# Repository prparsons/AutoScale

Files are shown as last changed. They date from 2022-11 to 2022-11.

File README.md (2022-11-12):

# AutoScale
Automatic electronic scale.  This has mainly just been a project for fun, started simply with getting a load cell working on an MSP430. Eventually decided to try and make an auto dispensing scale (powder/granules). It grew beyond the capability of the MSP pretty quickly, at which point I moved to a STM32F405. Then I replaced the 16x2 character display with a 320x240 LCD (using an spi interface, so we could ditch the MSP that was running the 16x2 display previously)

Consists of a dump chamber for bulk volume, and an auger to precisely top up to desired weight.  Initial test with just the auger here: https://youtu.be/iJeQbjNJ7Eg

I have tried several 3d printed builds for this, none of which never were terribly practical (3d printer not tight enough tolerances). Most recent version should be in the CAD folder (currently aiming for something that can be easily milled via 3 axis CNC, in addition to 3d printed). 

Code compiled using Ti CCS version 10 and STM32CubeIDE version 1.8.0

# Parts List
- Load Cell (TAL221 100g) https://www.sparkfun.com/products/14727
- Load Cell Amplifier (HX711) https://www.sparkfun.com/products/13879
- Precision Voltage Reference (LM4040) https://www.adafruit.com/product/2200
- Microcontrollers
  - STM32F4 (Currently using STM32F405) https://www.sparkfun.com/products/17713
  - MSP430 Launchpad (MSP430G2553) 
- Motors
  - Nema 17 motors
    - https://www.amazon.com/dp/B07LF898KN?ref=ppx_yo2_dt_b_product_details&th=1
    - https://www.amazon.com/dp/B094CQDDKF?psc=1&ref=ppx_yo2_dt_b_product_details
  - Stepper Driver (Toshiba TC78H670FTG) https://www.sparkfun.com/products/16836
- LCD Display
  - 2.4" 320x240 LCD Display using a IL9341 controller
    - https://www.waveshare.com/2.4inch-LCD-Module.htm  (also available on amazon)
- 4x4 Button Array
- Breadboard(s)
- Lots of jumper wires
- i2c pullup resistors (docs specify 10k ohm; currently using 2 2.2k in series and its working fine)
  
# Display Code
Using Waveshare's provided code for the LCD display ( https://www.waveshare.com/wiki/2.4inch_LCD_Module#Using_with_STM32 )

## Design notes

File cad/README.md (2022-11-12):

Current auger is offset, that isn't necessary anymore, but doesn't really matter for now (it works fine offset).

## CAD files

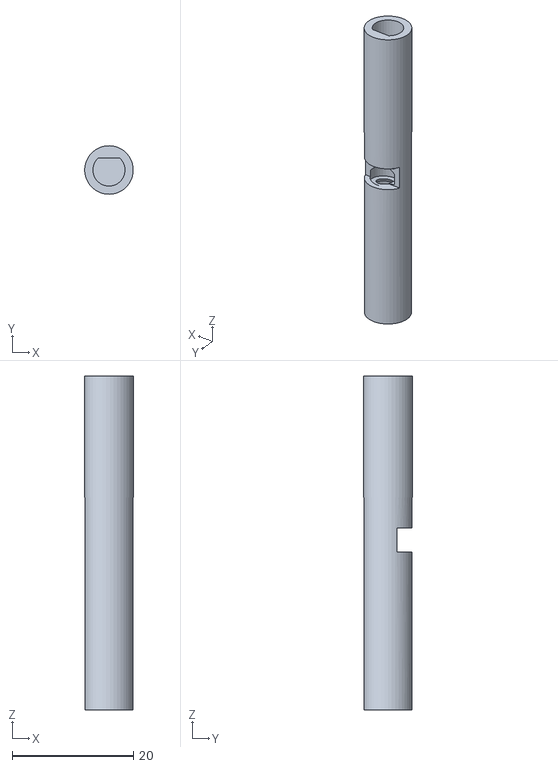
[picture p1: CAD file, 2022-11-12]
cad/measure_auger_tube.stl
7.99 x 7.99 x 55.0

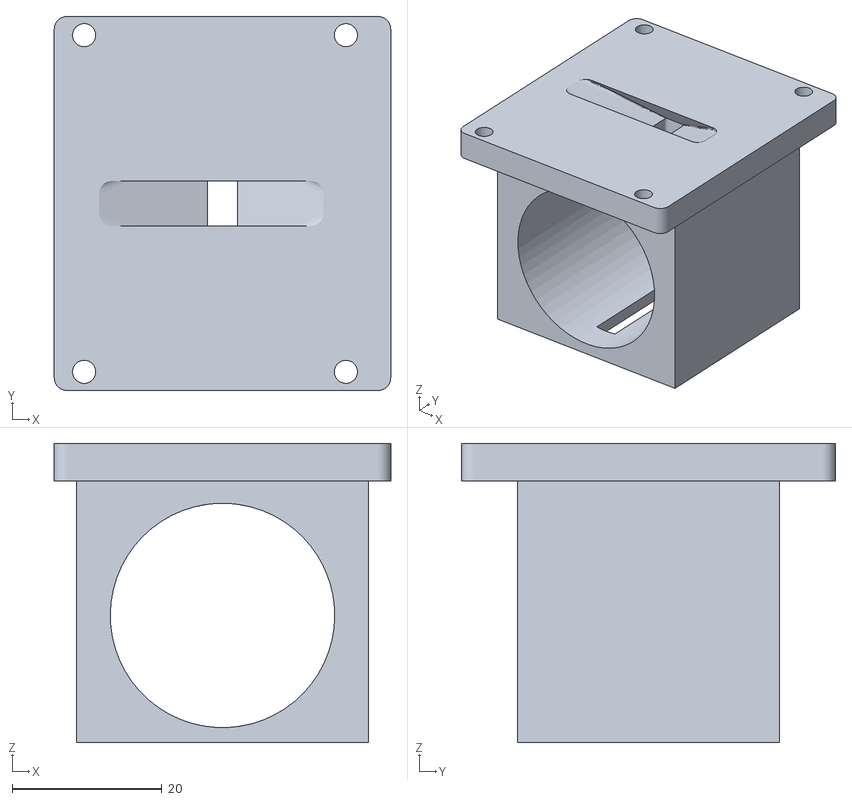
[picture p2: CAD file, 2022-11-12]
cad/measure_dump_body.stl
45.0 x 50.0 x 40.0

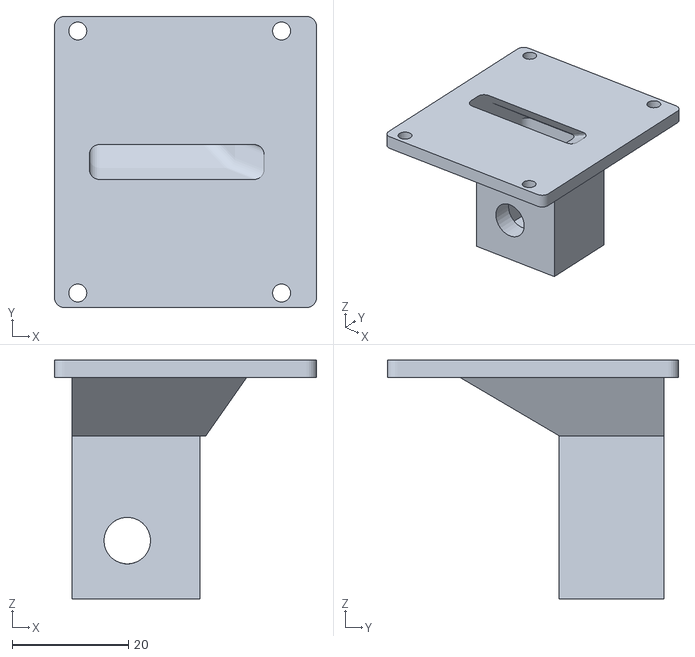
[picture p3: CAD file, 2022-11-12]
cad/measure_auger_body.stl
45.0 x 50.0 x 41.0

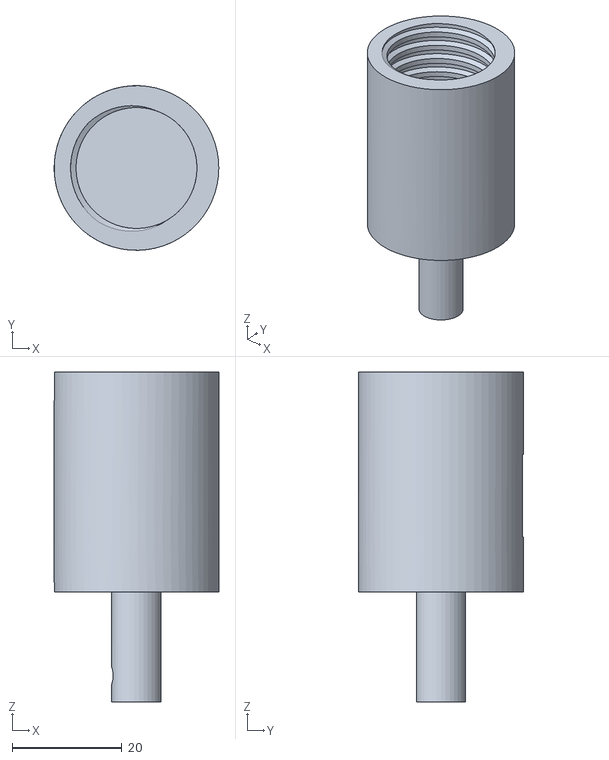
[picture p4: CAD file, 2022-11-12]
cad/measure_dump_tube.stl
29.9 x 29.9 x 60.0

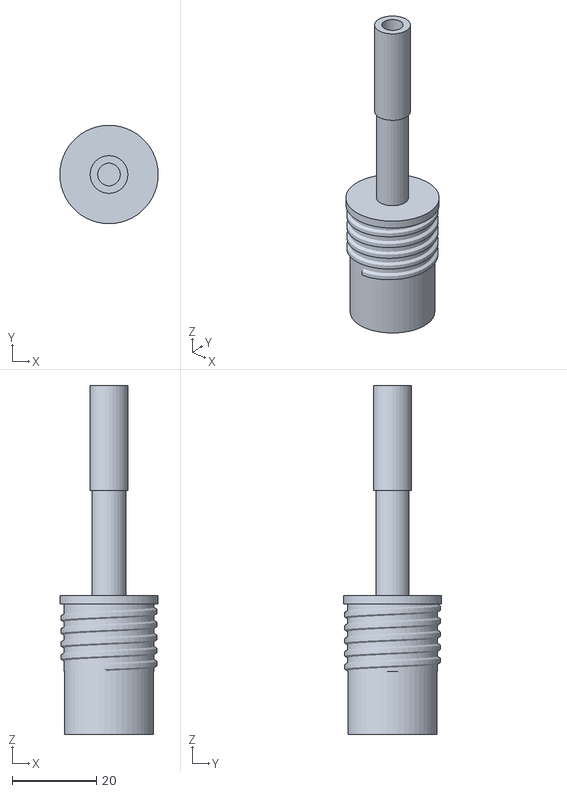
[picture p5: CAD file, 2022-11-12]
cad/measure_dump_plug.stl
23.4 x 23.4 x 83.0

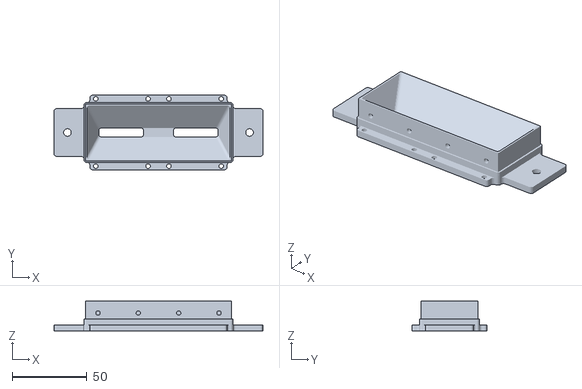
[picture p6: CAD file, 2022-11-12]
cad/measure_base.stl
140.0 x 50.0 x 20.0

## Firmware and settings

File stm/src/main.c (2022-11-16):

/* USER CODE BEGIN Header */
//       [STM32F405 Pin, ThingPlus Pin]
// PC0   [8, 8 D0]
//    Input to read the load cell
// PC1   [9, 7 D1]
//    Output to write clk to drive load cell "serial"
//
//
// GPIO
//    - https://simonmartin.ch/resources/stm32/dl/STM32%20Tutorial%2001%20-%20GPIO%20Operations%20using%20HAL%20(and%20FreeRTOS).pdf
//
// Timer idea for delay
//    - https://controllerstech.com/create-1-microsecond-delay-stm32/
//    - https://www.digikey.com/en/maker/projects/getting-started-with-stm32-timers-and-timer-interrupts/d08e6493cefa486fb1e79c43c0b08cc6
//
/*
 * Explanation
 *  Uses an hx711, basically a 24bit ADC. Interface is it's own kind of serial setup.
 *  -Wait until DAT is low (indicates it's ready). Sample is read MSB to LSB.
 *      Wait at least 0.1 microsecond until starting
 *  -We set CLK high, on it's rising edge (0.1microsecond max delay) DAT will have the next bit ready.
 *      CLK high time 0.2 - 50 microsecond
 *      CLK low time min 0.2 microsecond (1 typical)
 *  -Gain is set by how many pulses we send (DAT is pulled high by 25th pulse
 *      Pulse   Gain
 *      25      128
 *      26      32
 *      27      64
 *
 *
 * Pinout
 *  ThingPlus  ->  Load Cell Amplifier
 *  D0         ->   DAT
 *  D1         ->   CLK
 *
 *  ThingPlus  ->  Display MSP430G2553 (I2C)
 *  SCL        ->   P1.6 SCL
 *  SDA        ->   P1.7 SDA
 *
 *  Load Cell Amplifier
 *  VDD   ->   ThingPlus +3.3V
 *  VCC   ->   VREF +4.096V
 *
 *  Precision Voltage Ref (LM4040)
 *  VCC   ->   ThingPlus +3.3V
 *
 *
 * To add second stepper (and more), moved to ATP carrier board, didn't have to re-map anything,
 * though some of the board labels have changed. Labels below are all correct for ATP board.
 *
 *
 *  stepper driver 1
 *    en   pa8   g1
 *    stby pa0   g2
 *    0    pc8   g3
 *    1    pc9   g4
 *    2    pc13  g5
 *    3    pc2   g6
 *
 *  stepper driver 2
 *    en
 *    stby
 *    0
 *    1
 *    2
 *    3
 *
 *  LCD
 *    dc          pb0   a1
 *    rst         pc5   a0
 *    cs          pa4   i2s_ws
 *    pwm(timer)  pa2   tx1      (timer 5, channel 3)
 *  spi1
 *    mosi        pa7
 *    miso        pa6
 *    sck         pa5
 */
/* USER CODE END Header */
/* Includes ------------------------------------------------------------------*/
#include "main.h"

/* USER CODE BEGIN Includes */
#include <string.h>

#include "buttons.h"
#include "display.h"
#include "loadCell.h"
#include "motor.h"
#include "system.h"
/* USER CODE END Includes */

/* USER CODE BEGIN PD */
extern StepperMotor motorList[2];

MachineState currentState;

/* USER CODE END PD */

I2C_HandleTypeDef hi2c2;

SPI_HandleTypeDef hspi1;

TIM_HandleTypeDef htim1;
TIM_HandleTypeDef htim2;
TIM_HandleTypeDef htim3;
TIM_HandleTypeDef htim5;
TIM_HandleTypeDef htim8;

void SystemClock_Config(void);
static void MX_GPIO_Init(void);
static void MX_TIM1_Init(void);
static void MX_I2C2_Init(void);
static void MX_TIM8_Init(void);
static void MX_TIM2_Init(void);
static void MX_TIM3_Init(void);
static void MX_TIM5_Init(void);
static void MX_SPI1_Init(void);
/* USER CODE BEGIN 0 */
void timerDelay(uint16_t u16ths)
{
   __HAL_TIM_SET_COUNTER(&htim1,0);  // set the counter value a 0
   while (__HAL_TIM_GET_COUNTER(&htim1) < u16ths);  // wait for the counter to reach the input parameter
}

void statusBlink(enum LED_STATUS code)
{
   int iTimes;
   switch (code) {
      case LED_INIT_SUCCESS: {
         for (int i = 0; i < 2; i++) {
            HAL_GPIO_TogglePin(GPIOA, GPIO_PIN_15);
            HAL_Delay(250);
         }
         HAL_Delay(1000);
         iTimes = 2;
      } break;
      case LED_SAMPLE_SUCCESS:   iTimes = 4; break;
      case LED_SAMPLE_FAIL:      iTimes = 6; break;
      case LED_I2C_FAIL:         iTimes = 8; break;

      default: return;
   }
   for (int i = 0; i < iTimes; i++) {
      HAL_GPIO_TogglePin(GPIOA, GPIO_PIN_15);
      HAL_Delay(250);
   }
   HAL_Delay(1000);
   for (int i = 0; i < iTimes; i++) {
      HAL_GPIO_TogglePin(GPIOA, GPIO_PIN_15);
      HAL_Delay(250);
   }
}
/* USER CODE END 0 */

/**
  * @brief  The application entry point.
  * @retval int
  */
int main(void)
{
  /* MCU Configuration--------------------------------------------------------*/

  /* Reset of all peripherals, Initializes the Flash interface and the Systick. */
  HAL_Init();

  /* Configure the system clock */
  SystemClock_Config();

  /* Initialize all configured peripherals */
  MX_GPIO_Init();
  MX_TIM1_Init();
  MX_I2C2_Init();
  MX_TIM8_Init();
  MX_TIM2_Init();
  MX_TIM3_Init();
  MX_TIM5_Init();
  MX_SPI1_Init();
  /* USER CODE BEGIN 2 */
   if(HAL_I2C_Init(&hi2c2) != HAL_OK) {
      statusBlink(LED_I2C_FAIL);
   }
   buttonsInit(&hi2c2);
   servoInit(&htim8, TIM_CHANNEL_1, PWM0);

   displayInit_LCD(&hspi1, &htim5);
  /* USER CODE END 2 */

  /* Infinite loop */
  /* USER CODE BEGIN WHILE */
   HAL_TIM_Base_Start(&htim1);
   //__HAL_TIM_SET_COUNTER, HAL_TIM_Base_Start, HAL_TIM_Base_Start_IT, __HAL_TIM_SET_COMPARE
   // __HAL_TIM_GET_AUTORELOAD/__HAL_TIM_SET_AUTORELOAD
   // Compare is pulse width, counter is the actual counter
   /*
    * PWM Prescaler and Counter Period (PSC and ARR)
    * Frequency PWM = Freq Clock / ((ARR + 1)*(PSC + 1))
    *
    * desired frequency * ARR = timer frequency
    * PSC = (clock / timer frequency) - 1
    *
    * 50Hz = 64MHz / ((4999 + 1)*(255 + 1))
    *
    * Ideally want to maximize ARR (thats your max pulse width)
    * Close enough to 12bit with these values
    */
   //HAL_TIM_PWM_Start(&htim8, TIM_CHANNEL_1);

   statusBlink(LED_INIT_SUCCESS);
   HAL_Delay(3000);

   uint8_t u = 0;
   uint8_t uButton = 255;
   char cButton = 'x';
   currentState.bPWM0_Running = FALSE;
   currentState.iPWM0_Speed = 375; // 1.5ms (max value 4999), 500 == 2ms, 250 == 1ms
   currentState.displayMode = MAIN_MENU;
   currentState.scaleMode = SCALE_MODE_GRAM;
   currentState.iMeasureDumpDwell = 500;
   currentState.iMenuSelection = 0;
   currentState.fTargetWeight = 0;
   currentState.fTrayWeight = 2;
   currentState.iTricklePercent = 90;
   currentState.fGramPerCC = 10;
   currentState.iTrickle1RPMfast = 2;
   currentState.iTrcikle2RPMslow = 1;
   currentState.bMenuHighlight = FALSE;
   displaySwitchMode(&currentState, 0);

   stepTableInit();
   stepperInit(&htim3, &htim2);
   stepperConfig(&motorList[1], Step_32);
   stepperConfig(&motorList[0], Step_32);

   filterInit();

   CommandQueue.iHi = -1;
   CommandQueue.iStep[0] = -1;
   CommandQueue.iStep[1] = -1;

   while (1) {
      if (readCell()) {
         calculateAverage();
         currentState.fGrainsCurrent = getGrains();
         currentState.fGramsCurrent = getGrams();
         if (++u % 5 == 0) {
            displayUpdate_(&currentState);
         }
      }
      HAL_Delay(10);

      // Read Buttons
      uButton = getButton();
      if (uButton < 16) {
         cButton = convertButtonChar(uButton);
         // Green:      Run/Go/Enter
         // Red:        Stop/kill/done
         // F1:         Tare
         // F2:         Calibrate
         // F3:         Run Load
         if (cButton == 'r') {
            // Stop everything, quit whatever program...red is kill button
            if (currentState.bPWM0_Running) {
               servoStop(PWM0);
               currentState.bPWM0_Running = FALSE;
            }
            CommandQueue.iHi = -1;
            stepperEnable(&motorList[0], FALSE);
            stepperEnable(&motorList[1], FALSE);
            currentState.stepTrickle = STEPPER_OFF;
            // Go back to main menu
            if (currentState.scaleMode == SCALE_MODE_GRAIN) currentState.displayMode = SCALE_GRAIN;
            else currentState.displayMode = SCALE_GRAM;
            if (currentState.displayMode != MAIN_MENU) {
               Display_Mode prev = currentState.displayMode;
               currentState.displayMode = MAIN_MENU;
               displaySwitchMode(&currentState, prev);
            }
         } else if (cButton == 'a') {
            setTare();
         } else if (cButton == 'b') {
         } else if (cButton == 'c') {
         } else if (cButton == 'd') {
            int i = ++CommandQueue.iStep[0];
            CommandQueue.Q_Step[0][i].uCommand = STEP_CHAMBER_DUMP;
            CommandQueue.Q_Step[0][i].uButton[0] = currentState.iMeasureDumpDwell;
            i = ++CommandQueue.iStep[1];
            CommandQueue.Q_Step[1][i].uCommand = STEP_CHAMBER_DUMP;
            CommandQueue.Q_Step[1][i].uButton[0] = currentState.iMeasureDumpDwell;
         } else {
            runQueue(&currentState, uButton);
            uButton = convertButton(uButton);
            displayHandleMenu(&currentState, uButton, cButton);
         }
      } else {
         // Run current program
         runQueue(&currentState, 255);
      }
      runStepperQueue(&currentState, &motorList[0], CommandQueue.Q_Step[0], &CommandQueue.iStep[0]);
      runStepperQueue(&currentState, &motorList[1], CommandQueue.Q_Step[1], &CommandQueue.iStep[1]);

    /* USER CODE END WHILE */

    /* USER CODE BEGIN 3 */
   }
  /* USER CODE END 3 */
}

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
/* USER CODE BEGIN 4 */

void HAL_TIM_PeriodElapsedCallback(TIM_HandleTypeDef *htim)
{
   for (int i = 0; i < 2; i++) {
      if (htim == motorList[i].htim) {
         if (motorList[i].bStepOnTimer) {
            HAL_GPIO_WritePin(motorList[i].gpio_M2, motorList[i].m2, GPIO_PIN_RESET); //m2 == m_clk
            timerDelay(16);//that updates timer stuff without the config...

            if (motorList[i].timerIndexCurrent++ == motorList[i].timerIndexStop) {
               if (motorList[i].tableIndexCurrent == 0) {
                  motorList[i].bStepOnTimer = FALSE;
                  stepperEnable(&motorList[i], FALSE);
                  HAL_TIM_Base_Stop_IT(motorList[i].htim);
                  return;
               }

               motorList[i].timerIndexCurrent = 0;
               motorList[i].timerIndexStop = motorList[i].arStepper_Table[--motorList[i].tableIndexCurrent].iNumSteps;
               motorList[i].bStepOnTimer = motorList[i].arStepper_Table[motorList[i].tableIndexCurrent].bStep;
               if (motorList[i].arStepper_Table[motorList[i].tableIndexCurrent].bClockwise) {
                  stepperSetCW(&motorList[i]);
               } else {
                  stepperSetCCW(&motorList[i]);
               }

               __HAL_TIM_SET_AUTORELOAD(htim, motorList[i].arStepper_Table[motorList[i].tableIndexCurrent].uNewDelay);
               __HAL_TIM_SET_COUNTER(htim, 0xffffffff);
            }
            HAL_GPIO_WritePin(motorList[i].gpio_M2, motorList[i].m2, GPIO_PIN_SET);
         } else {
            if (motorList[i].timerIndexCurrent++ == motorList[i].timerIndexStop) {
               if (motorList[i].tableIndexCurrent == 0) {
                  motorList[i].bStepOnTimer = FALSE;
                  stepperEnable(&motorList[i], FALSE);
                  HAL_TIM_Base_Stop_IT(motorList[i].htim);
                  return;
               }

               motorList[i].timerIndexCurrent = 0;
               motorList[i].timerIndexStop = motorList[i].arStepper_Table[--motorList[i].tableIndexCurrent].iNumSteps;
               motorList[i].bStepOnTimer = motorList[i].arStepper_Table[motorList[i].tableIndexCurrent].bStep;
               if (motorList[i].arStepper_Table[motorList[i].tableIndexCurrent].bClockwise) {
                  stepperSetCW(&motorList[i]);
               } else {
                  stepperSetCCW(&motorList[i]);
               }

               __HAL_TIM_SET_AUTORELOAD(htim, motorList[i].arStepper_Table[motorList[i].tableIndexCurrent].uNewDelay);
               __HAL_TIM_SET_COUNTER(htim, 0xffffffff);
            }
         }
      }
   }
}
/* USER CODE END 4 */
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


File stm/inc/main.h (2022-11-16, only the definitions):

#define TRUE 1
#define FALSE 0
#define nullptr 0
#define ST0_M2_Pin GPIO_PIN_13
#define ST0_M2_GPIO_Port GPIOC
#define CELL_DAT_Pin GPIO_PIN_0
#define CELL_DAT_GPIO_Port GPIOC
#define CELL_CLK_Pin GPIO_PIN_1
#define CELL_CLK_GPIO_Port GPIOC
#define ST0_M3_Pin GPIO_PIN_2
#define ST0_M3_GPIO_Port GPIOC
#define ST0_STBY_Pin GPIO_PIN_0
#define ST0_STBY_GPIO_Port GPIOA
#define ST2_EN_Pin GPIO_PIN_3
#define ST2_EN_GPIO_Port GPIOA
#define CS_Pin GPIO_PIN_4
#define CS_GPIO_Port GPIOA
#define ST2_M3_Pin GPIO_PIN_4
#define ST2_M3_GPIO_Port GPIOC
#define RST_Pin GPIO_PIN_5
#define RST_GPIO_Port GPIOC
#define DC_Pin GPIO_PIN_0
#define DC_GPIO_Port GPIOB
#define ST2_STBY_Pin GPIO_PIN_1
#define ST2_STBY_GPIO_Port GPIOB
#define ST2_M1_Pin GPIO_PIN_12
#define ST2_M1_GPIO_Port GPIOB
#define ST2_M2_Pin GPIO_PIN_13
#define ST2_M2_GPIO_Port GPIOB
#define ST0_M0_Pin GPIO_PIN_8
#define ST0_M0_GPIO_Port GPIOC
#define ST0_M1_Pin GPIO_PIN_9
#define ST0_M1_GPIO_Port GPIOC
#define ST0_EN_Pin GPIO_PIN_8
#define ST0_EN_GPIO_Port GPIOA
#define ST2_M0_Pin GPIO_PIN_3
#define ST2_M0_GPIO_Port GPIOB
#define ST1_EN_Pin GPIO_PIN_4
#define ST1_EN_GPIO_Port GPIOB
#define ST1_STBY_Pin GPIO_PIN_5
#define ST1_STBY_GPIO_Port GPIOB
#define ST1_M0_Pin GPIO_PIN_6
#define ST1_M0_GPIO_Port GPIOB
#define ST1_M1_Pin GPIO_PIN_7
#define ST1_M1_GPIO_Port GPIOB
#define ST1_M2_Pin GPIO_PIN_8
#define ST1_M2_GPIO_Port GPIOB
#define ST1_M3_Pin GPIO_PIN_9
#define ST1_M3_GPIO_Port GPIOB

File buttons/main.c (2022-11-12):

#include "msp430g2553.h"


void initI2C();
void initButtons();

#define ADDRESS 0x46
#define false 0
#define true 1

unsigned char bSendButton = false;
unsigned char uRegister;
unsigned char arButtonBuffer[8];
unsigned char uButtonIndex = 0;
unsigned char uButtonSize = 0;

unsigned char arButtonBits[] = { BIT0, BIT1, BIT2, BIT3 };


/****************************************************************************
 * Pinout
 *  p1.0    Output Col 1
 *  p1.1    Output Col 2
 *  p1.2    Output Col 3
 *  p1.3    Output Col 4
 *  p1.6    SCL
 *  p1.7    SDA
 *
 *  p2.0    Input Row 1
 *  p2.1    Input Row 2
 *  p2.2    Input Row 3
 *  p2.3    Input Row 4
 ****************************************************************************/
void main( void )
{
   WDTCTL = (WDTPW | WDTHOLD);                               // Stop watchdog timer

   initI2C();
   initButtons();

   __bis_SR_register( GIE );                                 // Enable global interrupts

   while (true) {
      __bis_SR_register(CPUOFF + GIE);        // Enter LPM0 w/ interrupts
   }
}

void initI2C()
{
   P1SEL |= BIT6 + BIT7;                     // Assign I2C pins to USCI_B0
   P1SEL2 |= BIT6 + BIT7;                     // Assign I2C pins to USCI_B0

   UCB0CTL1 |= UCSWRST;                      // Enable SW reset
   UCB0CTL0 = UCMODE_3 + UCSYNC;             // I2C slave, synchronous mode
   UCB0I2COA = ADDRESS;                      // Set Address
   UCB0CTL1 &= ~UCSWRST;                     // Clear SW reset, resume operation

   IE2 |=  UCB0RXIE;   //
}

void initButtons()
{
   // Output
   P1DIR |= BIT0 + BIT1 + BIT2 + BIT3;     // Set to output
   P1OUT |= BIT0 + BIT1 + BIT2 + BIT3;     // Output high

   // Input
   P2IE |=  BIT0 + BIT1 + BIT2 + BIT3;     // Enable interrupt
   P2IES &= ~(BIT0 + BIT1 + BIT2 + BIT3); // Low to high transition
   P2REN |= BIT0 + BIT1 + BIT2 + BIT3;    // Enable Pull Up/Down Resistors
   P2OUT &= ~(BIT0 + BIT1 + BIT2 + BIT3); // If Pull Up/Down are enabled, this determines which direction those are (0 pull down, 1 pull up)
   // Clear IFG
   P2IFG &= ~BIT0;
   P2IFG &= ~BIT1;
   P2IFG &= ~BIT2;
   P2IFG &= ~BIT3;

   // Timer to start listening again. Default 1mhz, we want 0.1sec
   // 1,000,000hz / 2 = 500,000hz
   // Set timer to 1/10 of that, 50000, we get 0.1 sec
   CCTL0 = CCIE;                             // CCR0 interrupt enabled
   CCR0 = 50000;                             // CCR0 value of 12500
   TACTL = TASSEL_2 + MC_0 + ID_3;//ID_1;                  // SMCLK, off for now, divider of 2
}

#pragma vector = USCIAB0TX_VECTOR
__interrupt void USCIAB0TX_ISR(void)
{
   if (bSendButton) {
      // Send byte
      UCB0TXBUF = arButtonBuffer[uButtonIndex++];
      bSendButton = false;
      IE2 &= ~UCB0TXIE;
   } else  {
      uRegister = UCB0RXBUF;

      if (uButtonIndex == uButtonSize) {
         uButtonIndex = 0;
         uButtonSize = 1;
         arButtonBuffer[0] = 255;
      }
      bSendButton = true;
      IE2 |= UCB0TXIE;                          // Enable i2c TX interrupt
   }
}

// Port 2 interrupt service routine
unsigned char button;
unsigned char bit;
unsigned char offset;
#pragma vector=PORT2_VECTOR
__interrupt void Port_2(void)
{
   P2IE &=  ~(BIT0 + BIT1 + BIT2 + BIT3); // Turn off interrupt
   P1OUT &=  ~(BIT0 + BIT1 + BIT2 + BIT3); // Turn off output

   if (P2IFG & BIT0) {
      bit = BIT0;
      offset = 0;
   } else if (P2IFG & BIT1) {
      bit = BIT1;
      offset = 4;
   } else if (P2IFG & BIT2) {
      bit = BIT2;
      offset = 8;
   } else {//if (P2IFG & BIT3) {
      bit = BIT3;
      offset = 12;
   }

   P2IFG &=  ~(BIT0 + BIT1 + BIT2 + BIT3);
   for (button = 0; button < 4; button++) {
      P1OUT |= arButtonBits[button];
      __delay_cycles(1);
      if (P2IN & bit) {
         break;
      }
      P1OUT &= ~arButtonBits[button];
   }
   // If we couldn't find a button, turn everything back on and return
   if (button == 4) {
      P1OUT |= BIT0 + BIT1 + BIT2 + BIT3; // Turn on output
      __delay_cycles(1);
      P2IE |=  BIT0 + BIT1 + BIT2 + BIT3; // Turn on interrupt
      return;
   }

   P1OUT &= ~arButtonBits[button];
   if (uButtonIndex == uButtonSize) {
      uButtonIndex = 0;
      uButtonSize = 1;
      arButtonBuffer[0] = button + offset;
   } else {
      arButtonBuffer[uButtonSize++] = button + offset;
   }

   TACTL |= MC_2; // Start the timer
}

// Timer A0 interrupt service routine
#pragma vector=TIMER0_A0_VECTOR
__interrupt void Timer_A (void)
{
   TACTL &= ~MC_3; // Turns it off
   P1OUT |= BIT0 + BIT1 + BIT2 + BIT3; // Turn on output
   __delay_cycles(1);
   P2IE |=  BIT0 + BIT1 + BIT2 + BIT3; // Turn on interrupt
}

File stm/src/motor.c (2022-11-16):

#include "motor.h"

// Servo (PWM)
TIM_HandleTypeDef* arServoHandles[] = { nullptr, nullptr };
int arServoChannels[] = { 0, 0 };

// Indefinite number of steps in these tables (set the numsteps to -1, manually adjust stepper index)
stepperTimerTable stepper_TableSimple[7]; // Simple speed up, slow down
stepperTimerTable stepper_TableTwoStage[16]; // Multi stage slow down
stepperTimerTable stTable_32_180_simple[11];
stepperTimerTable stTable_32_30_moveCW[5];
stepperTimerTable stTable_32_30_moveCCW[5];

StepperMotor motorList[2];

void servoInit(TIM_HandleTypeDef* _pHandle, int iChannel, enum MOTOR_PWM motor)
{
   arServoHandles[motor] = _pHandle;
   arServoChannels[motor] = iChannel;
}

void servoStart(enum MOTOR_PWM motor)
{
   HAL_TIM_PWM_Start(arServoHandles[motor], arServoChannels[motor]);
}

void servoStop(enum MOTOR_PWM motor)
{
   HAL_TIM_PWM_Stop(arServoHandles[motor], arServoChannels[motor]);
}

void servoSetSpeed(enum MOTOR_PWM motor, int iSpeed, bool bRunning)
{
   if (bRunning) HAL_TIM_PWM_Stop(arServoHandles[motor], arServoChannels[motor]); // stop generation of pwm

   TIM_OC_InitTypeDef sConfigOC;
   sConfigOC.OCMode = TIM_OCMODE_PWM1;
   sConfigOC.Pulse = iSpeed;
   sConfigOC.OCPolarity = TIM_OCPOLARITY_HIGH;
   sConfigOC.OCNPolarity = TIM_OCNPOLARITY_HIGH;
   sConfigOC.OCFastMode = TIM_OCFAST_DISABLE;
   sConfigOC.OCIdleState = TIM_OCIDLESTATE_RESET;
   sConfigOC.OCNIdleState = TIM_OCNIDLESTATE_RESET;
   if (HAL_TIM_PWM_ConfigChannel(arServoHandles[motor], &sConfigOC, arServoChannels[motor]) != HAL_OK) Error_Handler();

   if (bRunning) HAL_TIM_PWM_Start(arServoHandles[motor], arServoChannels[motor]); // start pwm generation

}

void stepTableInit()
{
   stTable_32_30_moveCW[4].iNumSteps = 57;
   stTable_32_30_moveCW[3].iNumSteps = 256;
   stTable_32_30_moveCW[2].iNumSteps = 334;
   stTable_32_30_moveCW[1].iNumSteps = 256;
   stTable_32_30_moveCW[0].iNumSteps = 57;
   stTable_32_30_moveCW[4].uNewDelay = 14000;
   stTable_32_30_moveCW[3].uNewDelay = 3125;
   stTable_32_30_moveCW[2].uNewDelay = 2500;
   stTable_32_30_moveCW[1].uNewDelay = 3125;
   stTable_32_30_moveCW[0].uNewDelay = 14000;
   stTable_32_30_moveCW[4].bClockwise = TRUE;
   stTable_32_30_moveCW[3].bClockwise = TRUE;
   stTable_32_30_moveCW[2].bClockwise = TRUE;
   stTable_32_30_moveCW[1].bClockwise = TRUE;
   stTable_32_30_moveCW[0].bClockwise = TRUE;
   stTable_32_30_moveCW[4].bStep = TRUE;
   stTable_32_30_moveCW[3].bStep = TRUE;
   stTable_32_30_moveCW[2].bStep = TRUE;
   stTable_32_30_moveCW[1].bStep = TRUE;
   stTable_32_30_moveCW[0].bStep = TRUE;

   stTable_32_30_moveCCW[4].iNumSteps = 57;
   stTable_32_30_moveCCW[3].iNumSteps = 256;
   stTable_32_30_moveCCW[2].iNumSteps = 334;
   stTable_32_30_moveCCW[1].iNumSteps = 256;
   stTable_32_30_moveCCW[0].iNumSteps = 57;
   stTable_32_30_moveCCW[4].uNewDelay = 14000;
   stTable_32_30_moveCCW[3].uNewDelay = 3125;
   stTable_32_30_moveCCW[2].uNewDelay = 2500;
   stTable_32_30_moveCCW[1].uNewDelay = 3125;
   stTable_32_30_moveCCW[0].uNewDelay = 14000;
   stTable_32_30_moveCCW[4].bClockwise = FALSE;
   stTable_32_30_moveCCW[3].bClockwise = FALSE;
   stTable_32_30_moveCCW[2].bClockwise = FALSE;
   stTable_32_30_moveCCW[1].bClockwise = FALSE;
   stTable_32_30_moveCCW[0].bClockwise = FALSE;
   stTable_32_30_moveCCW[4].bStep = TRUE;
   stTable_32_30_moveCCW[3].bStep = TRUE;
   stTable_32_30_moveCCW[2].bStep = TRUE;
   stTable_32_30_moveCCW[1].bStep = TRUE;
   stTable_32_30_moveCCW[0].bStep = TRUE;

   stTable_32_180_simple[10].iNumSteps = 57;
   stTable_32_180_simple[9].iNumSteps = 256;
   stTable_32_180_simple[8].iNumSteps = 2574;
   stTable_32_180_simple[7].iNumSteps = 256;
   stTable_32_180_simple[6].iNumSteps = 57;
   stTable_32_180_simple[5].iNumSteps = 99;
   stTable_32_180_simple[4].iNumSteps = 57;
   stTable_32_180_simple[3].iNumSteps = 256;
   stTable_32_180_simple[2].iNumSteps = 2574;
   stTable_32_180_simple[1].iNumSteps = 256;
   stTable_32_180_simple[0].iNumSteps = 57;

   stTable_32_180_simple[10].uNewDelay = 14000;
   stTable_32_180_simple[9].uNewDelay = 3125;
   stTable_32_180_simple[8].uNewDelay = 2500;
   stTable_32_180_simple[7].uNewDelay = 3125;
   stTable_32_180_simple[6].uNewDelay = 14000;
   stTable_32_180_simple[5].uNewDelay = 16000;
   stTable_32_180_simple[4].uNewDelay = 14000;
   stTable_32_180_simple[3].uNewDelay = 3125;
   stTable_32_180_simple[2].uNewDelay = 2500;
   stTable_32_180_simple[1].uNewDelay = 3125;
   stTable_32_180_simple[0].uNewDelay = 14000;

   stTable_32_180_simple[10].bClockwise = TRUE;
   stTable_32_180_simple[9].bClockwise = TRUE;
   stTable_32_180_simple[8].bClockwise = TRUE;
   stTable_32_180_simple[7].bClockwise = TRUE;
   stTable_32_180_simple[6].bClockwise = TRUE;
   stTable_32_180_simple[5].bClockwise = TRUE;
   stTable_32_180_simple[4].bClockwise = FALSE;
   stTable_32_180_simple[3].bClockwise = FALSE;
   stTable_32_180_simple[2].bClockwise = FALSE;
   stTable_32_180_simple[1].bClockwise = FALSE;
   stTable_32_180_simple[0].bClockwise = FALSE;

   stTable_32_180_simple[10].bStep = TRUE;
   stTable_32_180_simple[9].bStep = TRUE;
   stTable_32_180_simple[8].bStep = TRUE;
   stTable_32_180_simple[7].bStep = TRUE;
   stTable_32_180_simple[6].bStep = TRUE;
   stTable_32_180_simple[5].bStep = FALSE;
   stTable_32_180_simple[4].bStep = TRUE;
   stTable_32_180_simple[3].bStep = TRUE;
   stTable_32_180_simple[2].bStep = TRUE;
   stTable_32_180_simple[1].bStep = TRUE;
   stTable_32_180_simple[0].bStep = TRUE;

   stepper_TableSimple[4].iNumSteps = 16;
   stepper_TableSimple[3].iNumSteps = 16;
   stepper_TableSimple[2].iNumSteps = 6400;
   stepper_TableSimple[1].iNumSteps = 3200;
   stepper_TableSimple[0].iNumSteps = 1600;
   stepper_TableSimple[4].uNewDelay = 32768;
   stepper_TableSimple[3].uNewDelay = 16384;
   stepper_TableSimple[2].uNewDelay = 8192;
   stepper_TableSimple[1].uNewDelay = 16384;
   stepper_TableSimple[0].uNewDelay = 32768;
   stepper_TableSimple[4].bClockwise = FALSE;
   stepper_TableSimple[3].bClockwise = FALSE;
   stepper_TableSimple[2].bClockwise = FALSE;
   stepper_TableSimple[1].bClockwise = FALSE;
   stepper_TableSimple[0].bClockwise = FALSE;
   stepper_TableSimple[4].bStep = TRUE;
   stepper_TableSimple[3].bStep = TRUE;
   stepper_TableSimple[2].bStep = TRUE;
   stepper_TableSimple[1].bStep = TRUE;
   stepper_TableSimple[0].bStep = TRUE;
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

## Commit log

2022-11-12 button file
2022-11-12 button circuit schematic
2022-11-12 rest of the physical body files
    [measure_auger_body.stl, measure_auger_tube.stl, measure_dump_body.stl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]

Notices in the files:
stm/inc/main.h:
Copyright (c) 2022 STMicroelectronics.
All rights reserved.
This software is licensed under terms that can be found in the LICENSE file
